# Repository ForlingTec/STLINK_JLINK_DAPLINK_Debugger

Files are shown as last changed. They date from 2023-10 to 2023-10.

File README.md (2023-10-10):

## 作者

**风陵：**

github:https://github.com/ForlingTec

CSDN:https://blog.csdn.net/weixin_42518229

**化作尘：**

https://blog.csdn.net/mbs520

## 一、产品介绍
该产品是一款基于USB2.0接口支持多个公司及多种内核的仿真器/编程器，板载了USB HUB、CPLD芯片，集成了DAPLink V2 & STLink V2 & JLink V9.7 & CDC虚拟串口/USB转串口四合一功能，硬件匹配选择的调试器并自动切换输出信号，无需重复更换固件和调试器，真正做到一机多用。

## 二、产品说明

1. 采用沁恒CH334P USB HUB全速率USB2.0集线器，使得同时支持DAPLINK、STLINK、JLINK、USB to USART(默认不焊接)连接
2. 独立3.3V 500mA的LDO稳压电源输出，为目标板提供稳定电源
3. 三大调试器共用一个外部接口，通过CPLD(AG1280Q48)智能检测并切换信号输出
4. 默认自带CDC虚拟串口，也可外接USB转串口芯片(CH340E)，默认NC
5. USB、外部输出接口均连接了静电管，避免静电损坏硬件
6. PCB采用4层双面布局，紧凑整洁，外壳体积小巧，仅40 × 40 × 13mm，外观简洁
7. 使用9P MX2.54带锁扣连接线，并附带清晰的信号标识，不用担心连接不牢固、信号连接错误
8. 每个调试器都有单独的状态指示灯，让用户对产品所处的状态一目了然

## 三、硬件框图

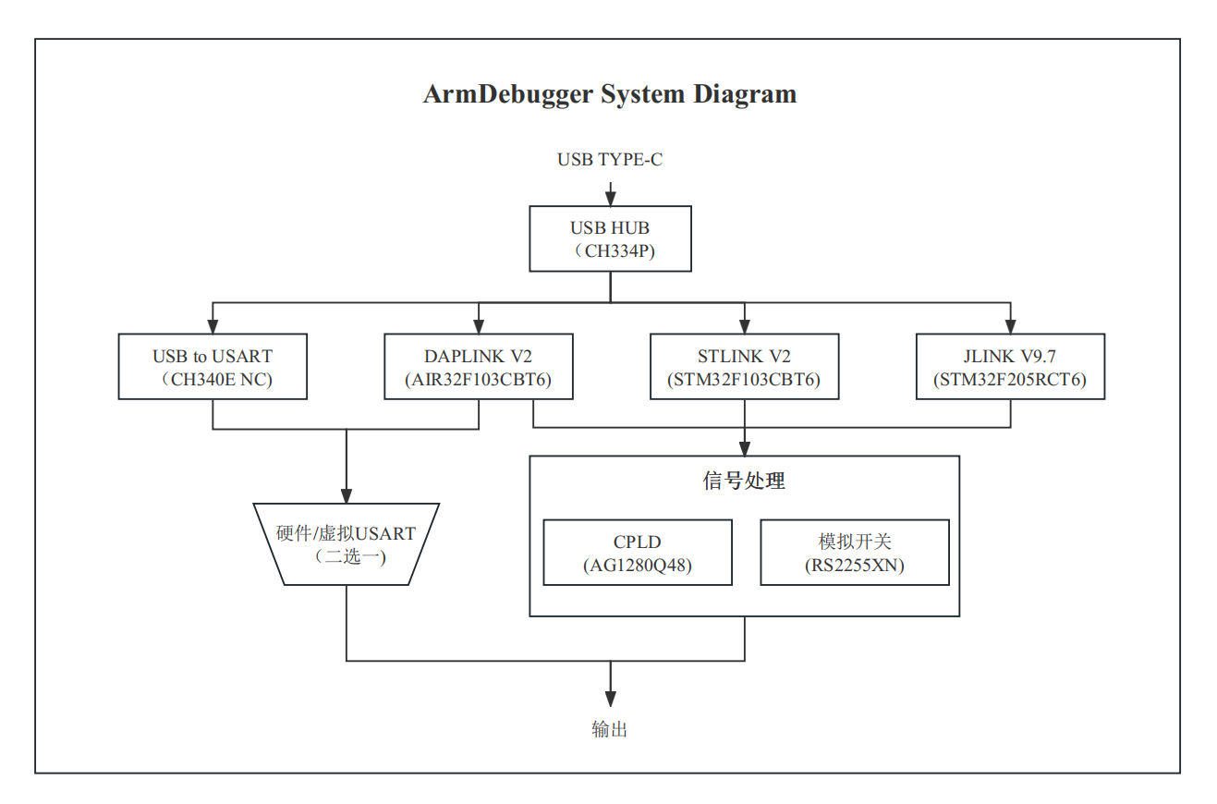
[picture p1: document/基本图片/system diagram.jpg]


## 四、产品使用

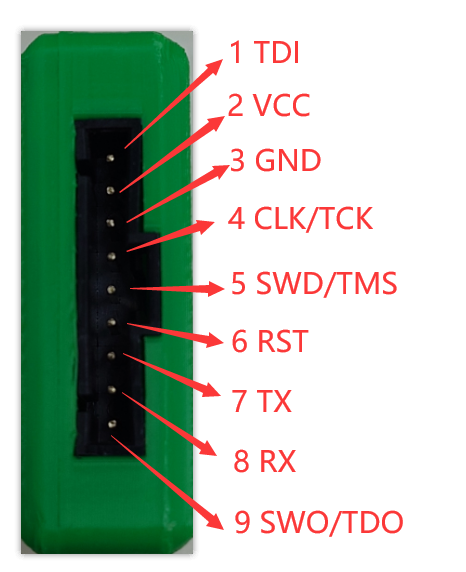
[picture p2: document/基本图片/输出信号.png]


安装完JLINK、STLINK等驱动，一般常用的KEIL/IAR等常用IDE会集成这些驱动程序，插入TYPE-C线，设备管理器显示以下新增设备

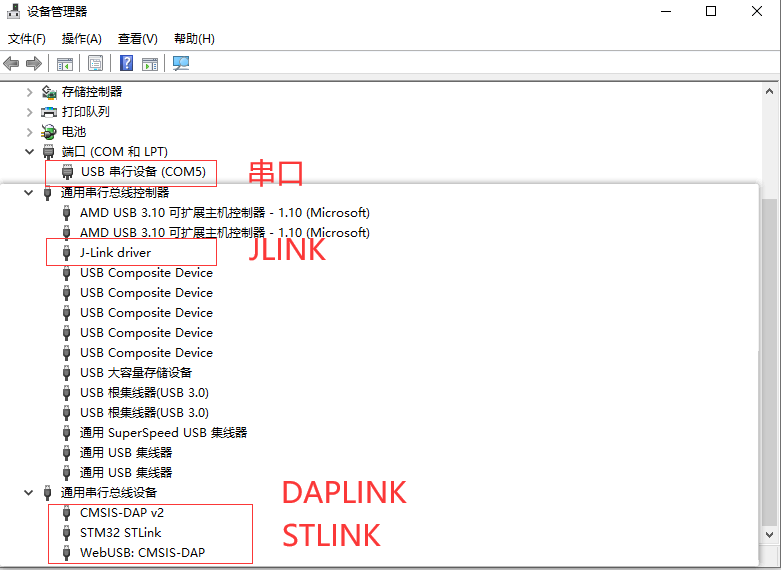
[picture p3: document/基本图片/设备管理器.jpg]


其中在KEIL中，将调试器与板子正常连接，选择调试器类型，会正常识别目标芯片(图中连接的芯片为STM32G0系列)，如下图

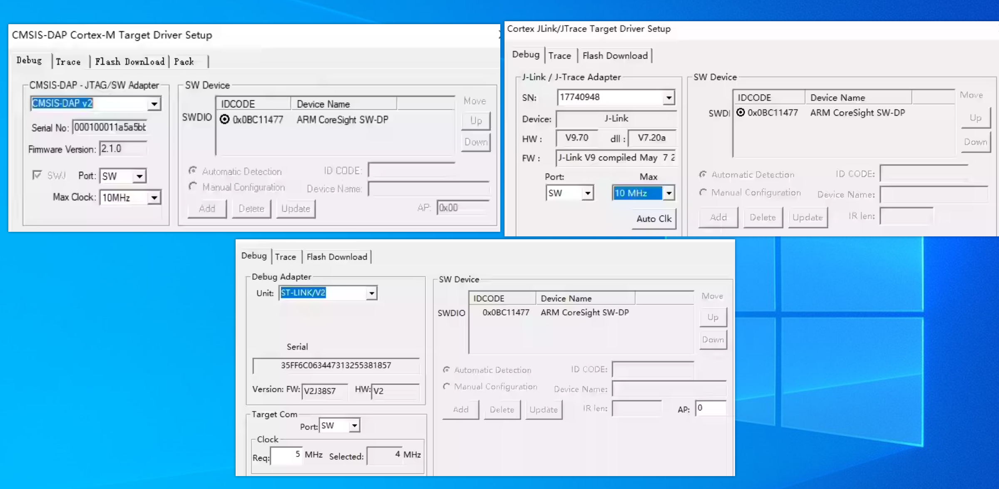
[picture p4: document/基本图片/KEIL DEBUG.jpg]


## 五、产品外观

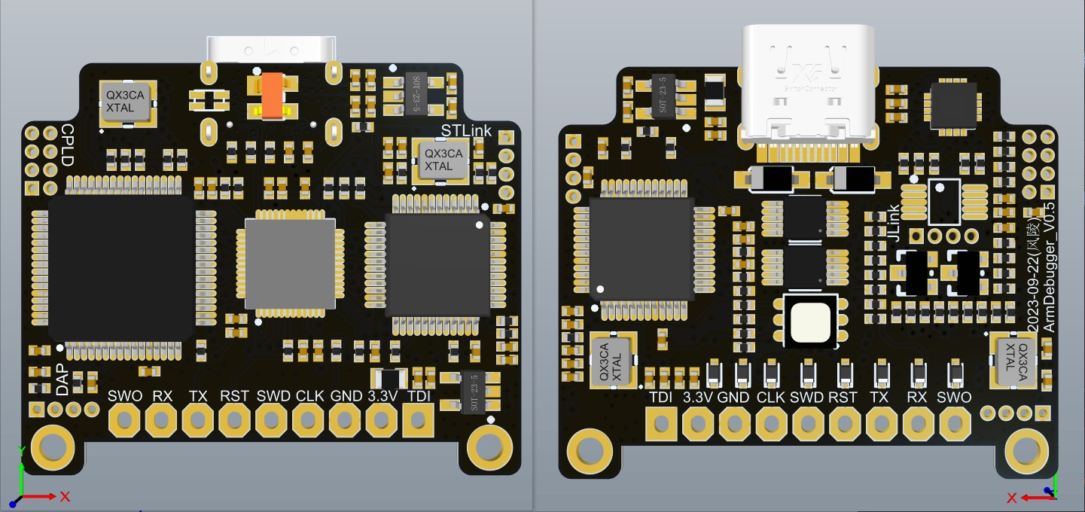
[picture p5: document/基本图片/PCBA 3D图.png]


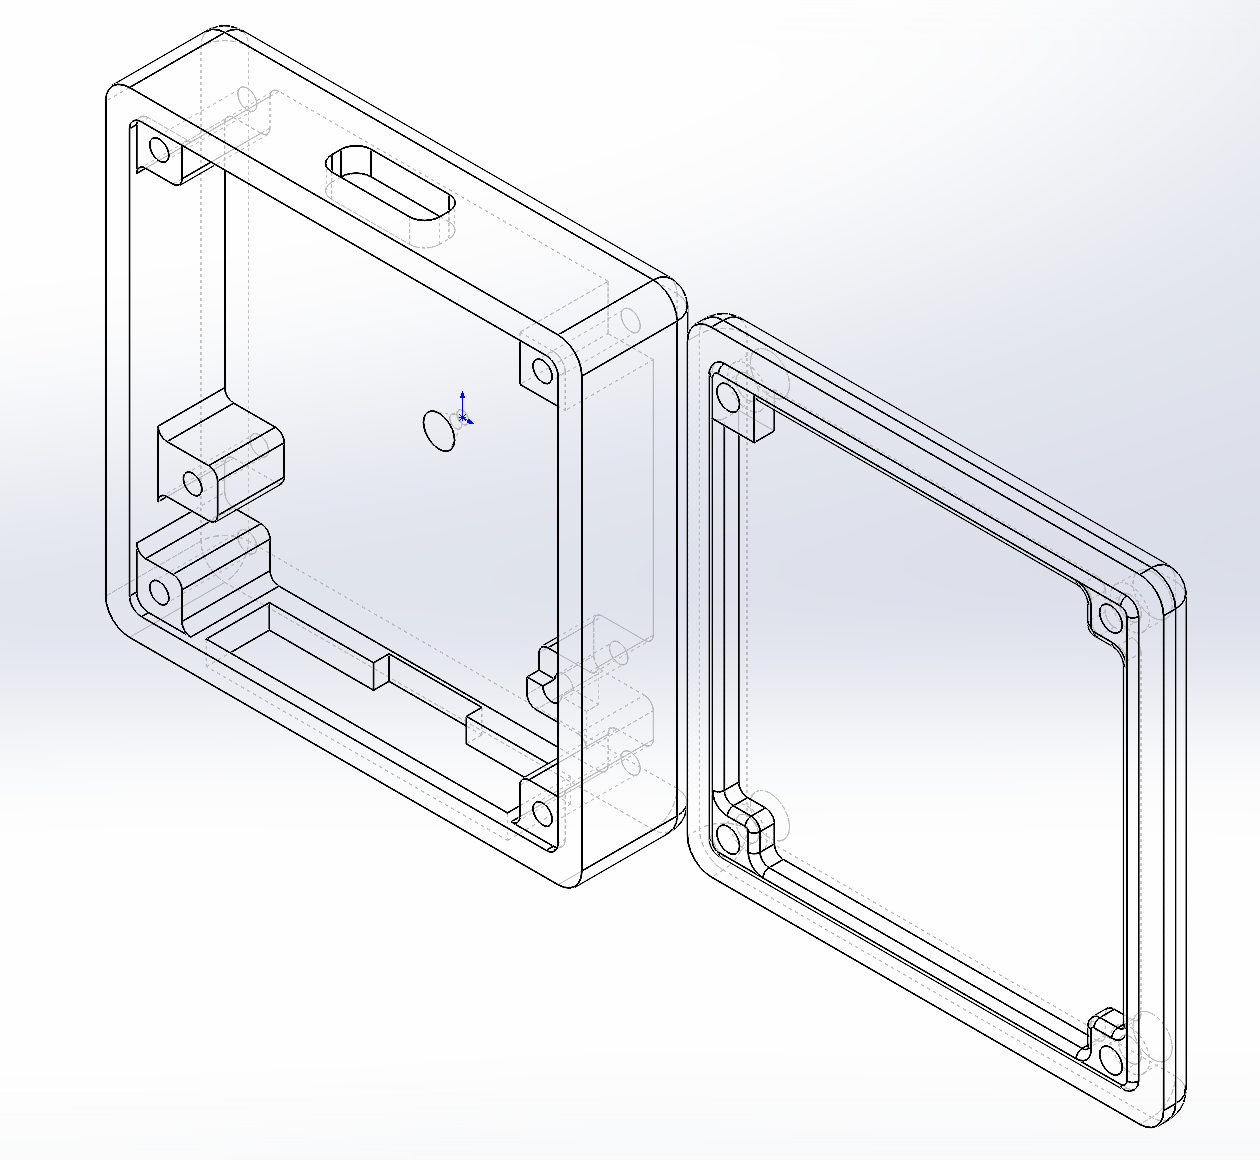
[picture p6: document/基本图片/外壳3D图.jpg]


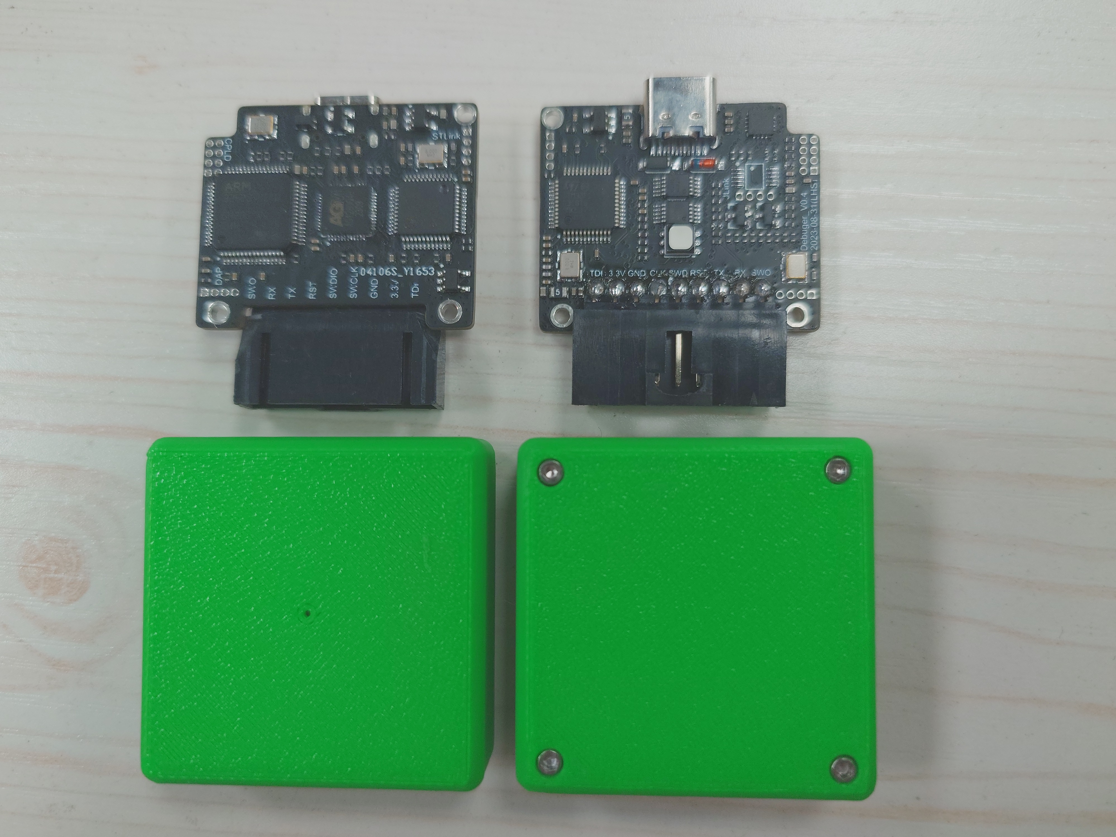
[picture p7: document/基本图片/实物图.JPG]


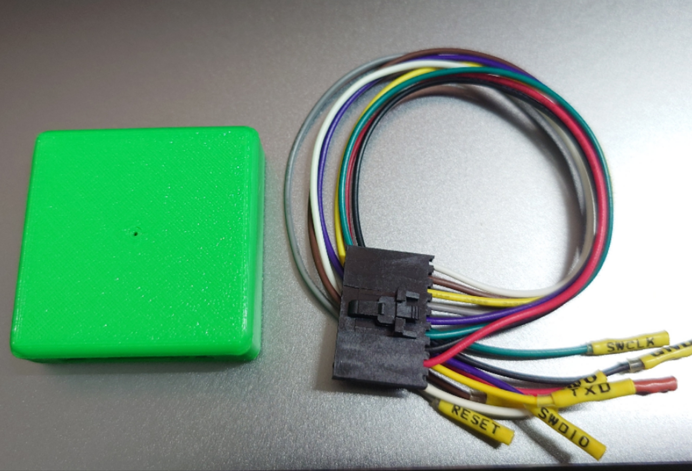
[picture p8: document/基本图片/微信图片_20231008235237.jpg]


## 六、软硬件设计

STLINK、JLINK均基于立创开源广场已有项目整理而来，DAPLINK基于合宙DAPLINK项目https://wiki.luatos.com/chips/air32f103/daplink.html整理得到。

硬件原理图与PCB工程按照模块划分，分POWER、USB HUB、STLINK、DAPLINK、JLINK、CPLD、PORT共7大模块组成。

软件设计主要是AG1280Q48这颗CPLD对信号的识别与处理，负责检测并切换当前有效的调试器，起到信号路由的作用。

CPLD软件工程用的是Quartus II + Supra混合开发,详情请查看AGM遨格芯官网:http://www.hizyuan.com/ProductDetail/2467472.html

## 七、固件烧录

需要连接TYPE-C线对硬件进行供电，推荐使用STLINK+STM32CubeProgrammer进行下载

**STM32CubeProgrammer加载bin文件，文件路径不能含有中文**

固件下载接口如下：详情请查看原理图与PCB

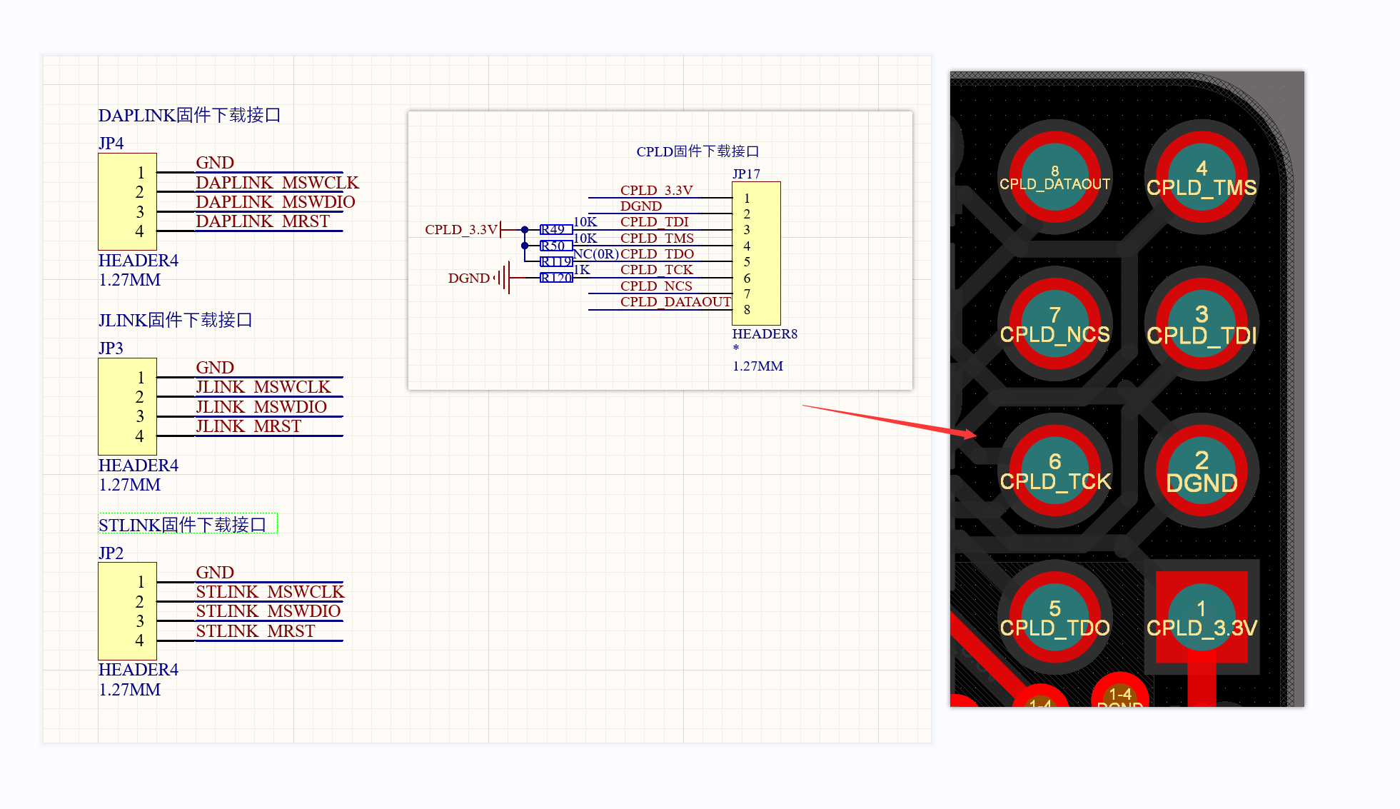
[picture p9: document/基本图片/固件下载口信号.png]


### STLINK

------

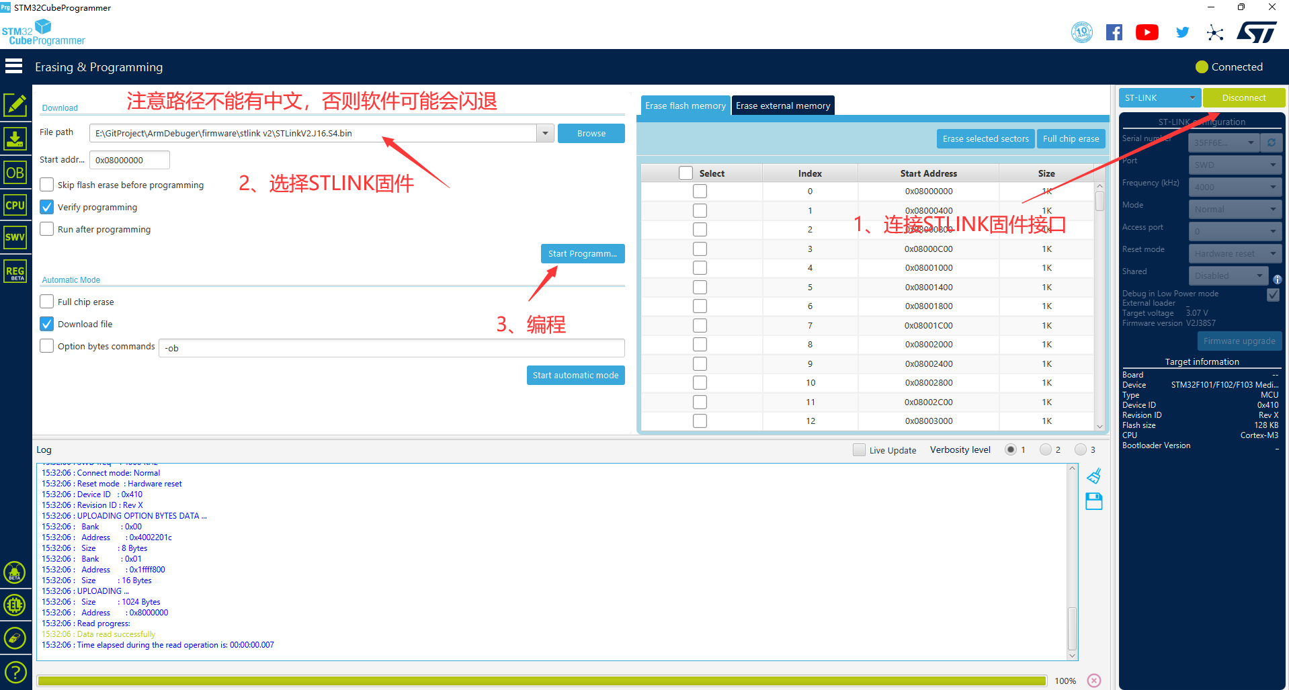
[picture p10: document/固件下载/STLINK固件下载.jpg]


### DAPLINK

------

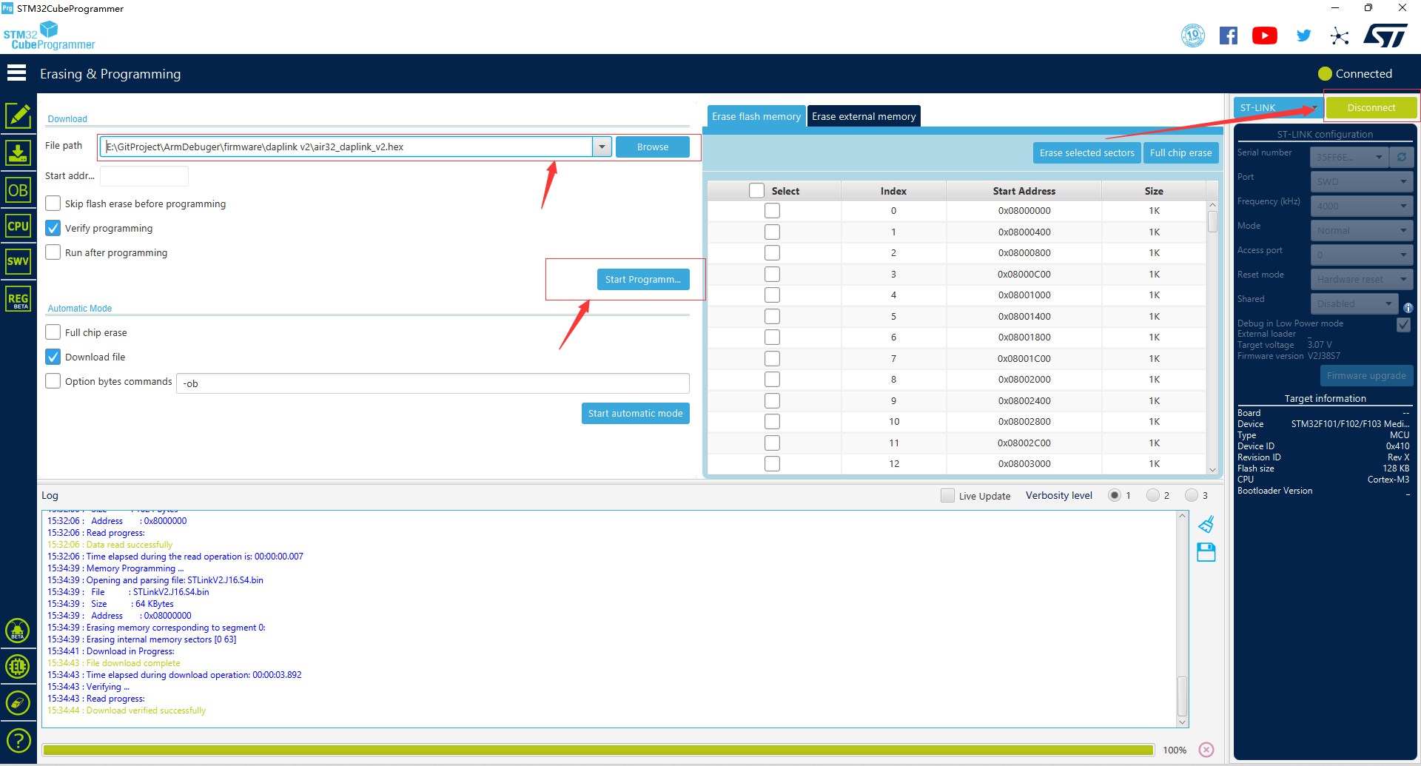
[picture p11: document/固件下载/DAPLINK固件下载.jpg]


### JLINK

------

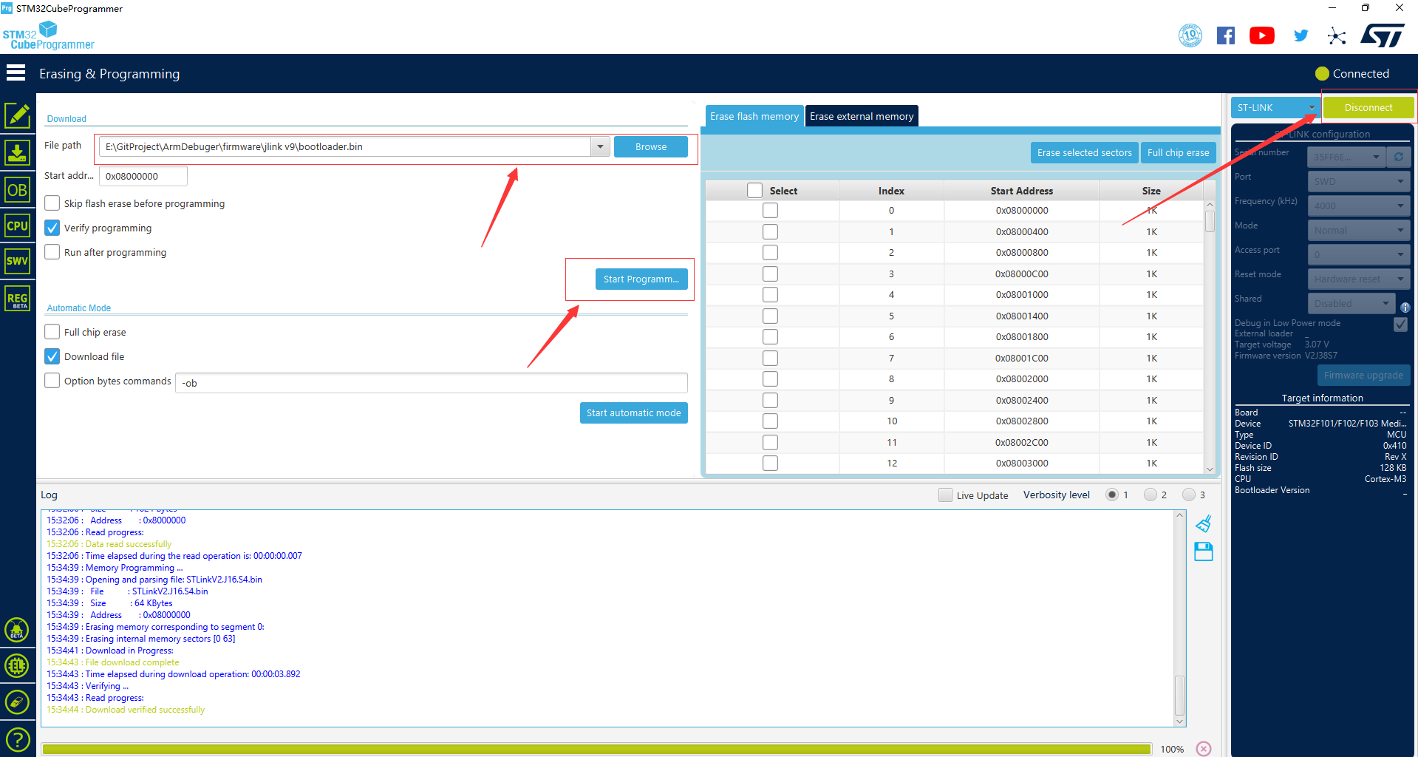
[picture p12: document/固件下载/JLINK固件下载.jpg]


### CPLD

------

1. 用Supra打开软件工程，点击左上角的“file - project - open project - AG1280.proj”，然后点击倒数第二个图标“program into device”打开烧录界面

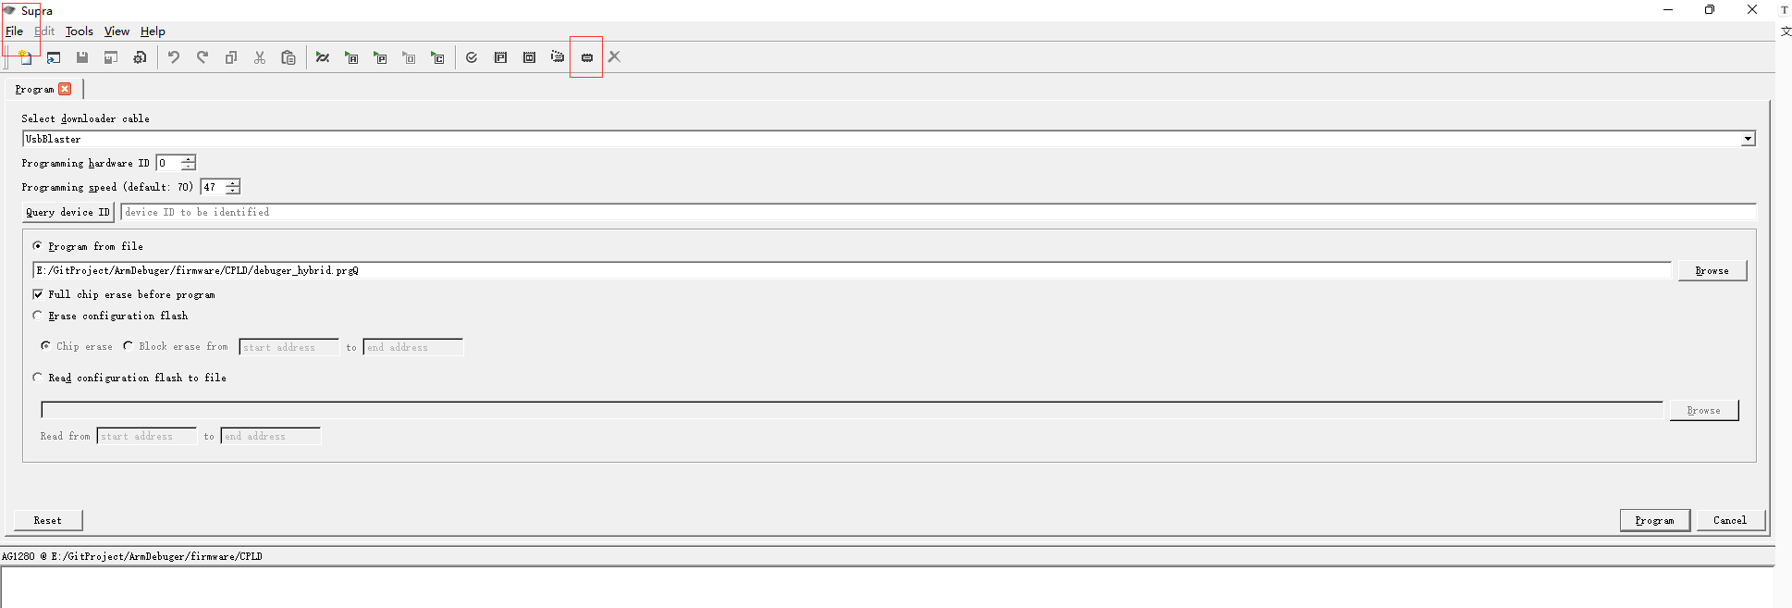
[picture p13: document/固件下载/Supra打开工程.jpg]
   

2. 将USB-blaster按照原理图上的信号连接好，按照以下步骤烧录CPLD固件

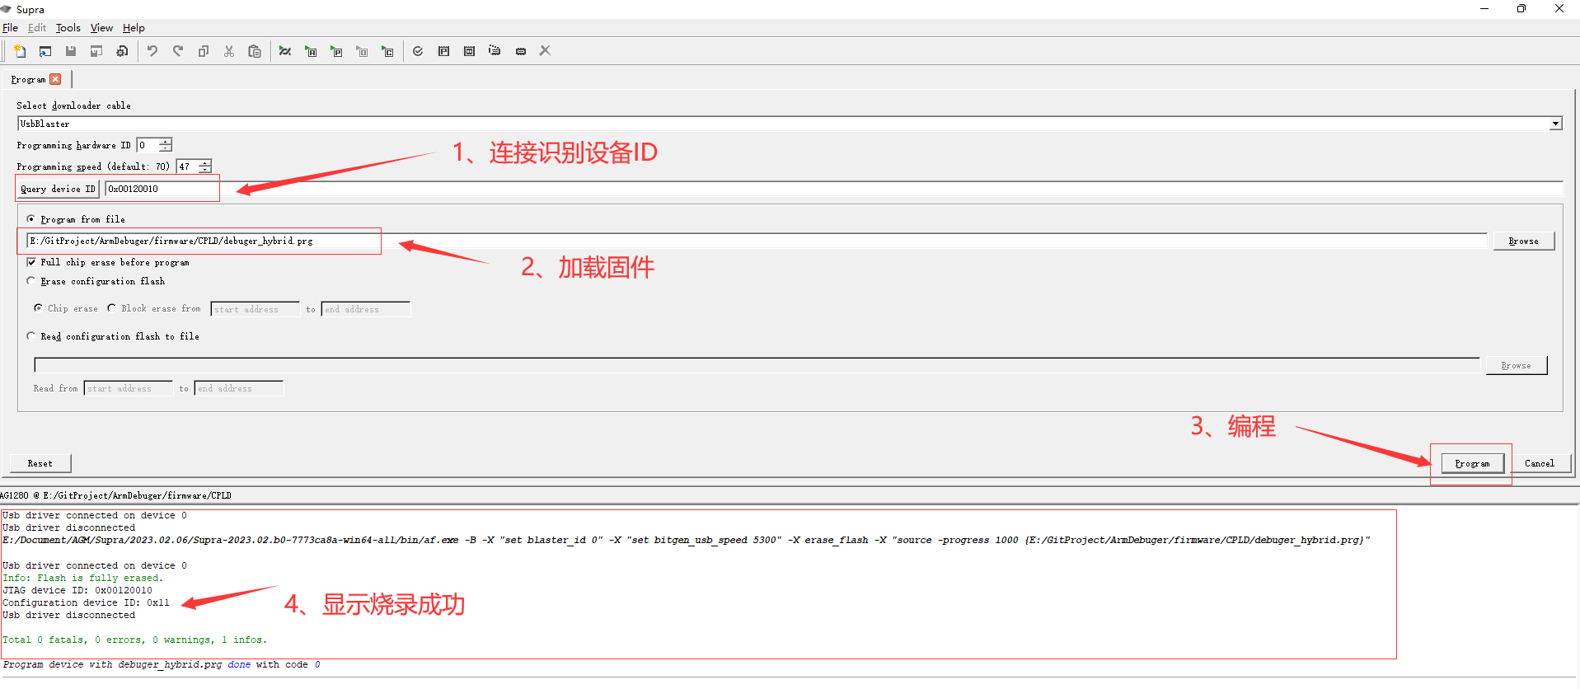
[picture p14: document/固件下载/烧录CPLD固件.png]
   

## 八、固件升级、License

步骤七烧录完固件后，重新插拔USB，这时候windows设备管理器就可以正常识别出设备了，可以查看**<<四、产品说明>>**的图片

### STLINK

------

因为步骤七烧录的STLINK的固件很旧，需要用STM32CubeProgrammer更新固件。

**1、重新打开STM32CubeProgrammer软件，进入固件升级界面**

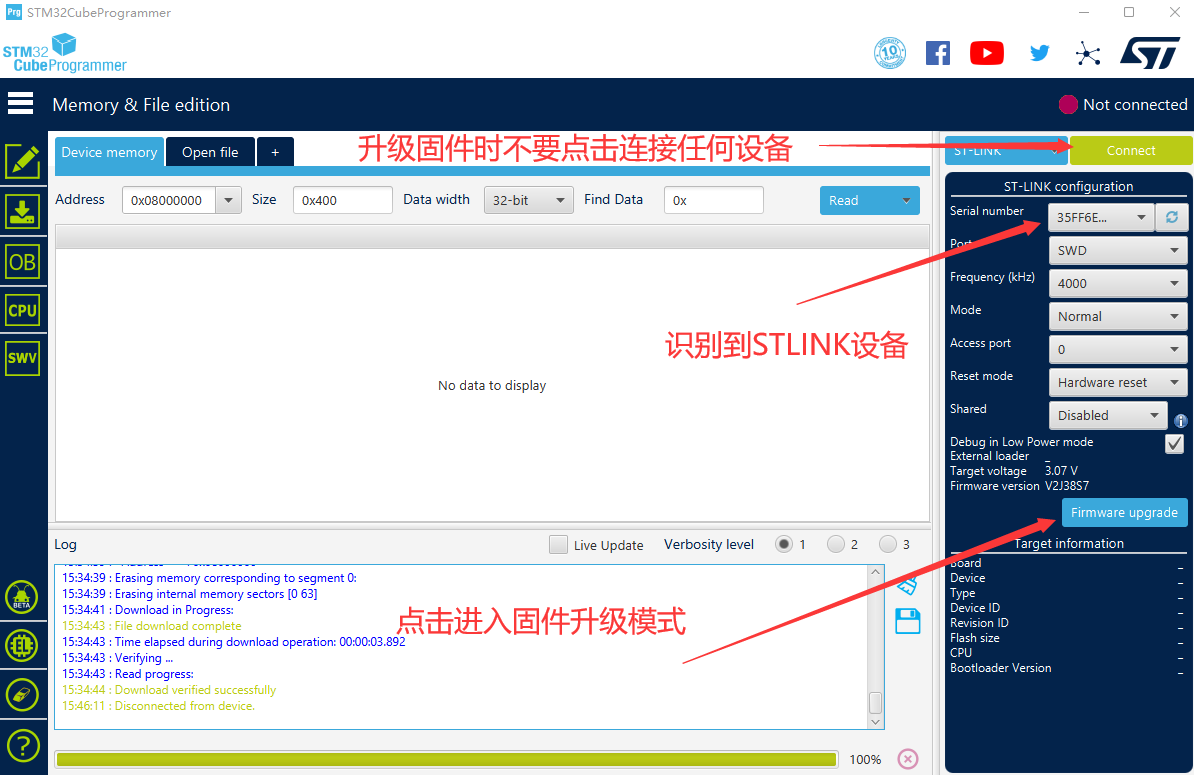
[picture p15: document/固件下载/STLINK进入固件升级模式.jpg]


**2、点击“Open in update mode”进入升级模式，识别到版本信息后点击“upgrade”升级按钮，等待升级完毕**

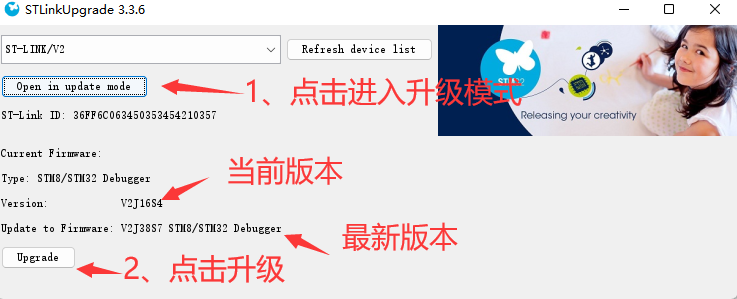
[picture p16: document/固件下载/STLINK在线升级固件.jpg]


### JLINK

------

**注意事项：JLINK驱动不能用V7.58以上版本，因为修复了盗版的BUG，容易掉固件，推荐用V7.2a及以下驱动版本**

烧录的JLINK固件仅仅是bootloader引导程序，需要用JLINK commander命令行先更新App固件，然后再添加license许可证，步骤如下：

1. 运行"jlink_license_creator.exe"程序

2. 如果没有“JLink_V6.32b.exe”、“JLinkARM.dll”这两个文件，直接点击“打开JLINK”按钮生成

3. 选择硬件版本，推荐用JLINK V9.7

4. 点击“生成”按钮，生成License SN号

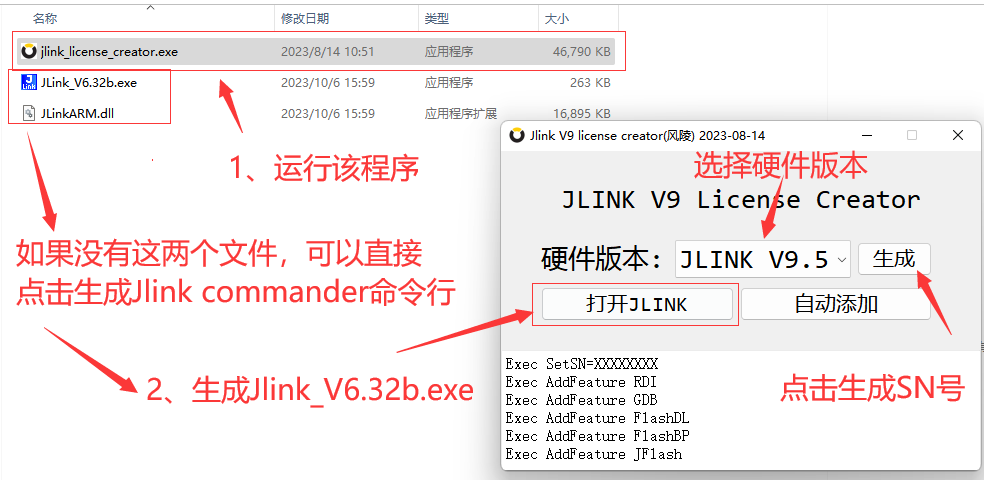
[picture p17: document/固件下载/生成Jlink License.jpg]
   

5. 运行“JLink_V6.32b.exe”程序，这时候会更新JLINK App固件，更新App完毕后将生成的S/N号和命令分别一条一条添加进去

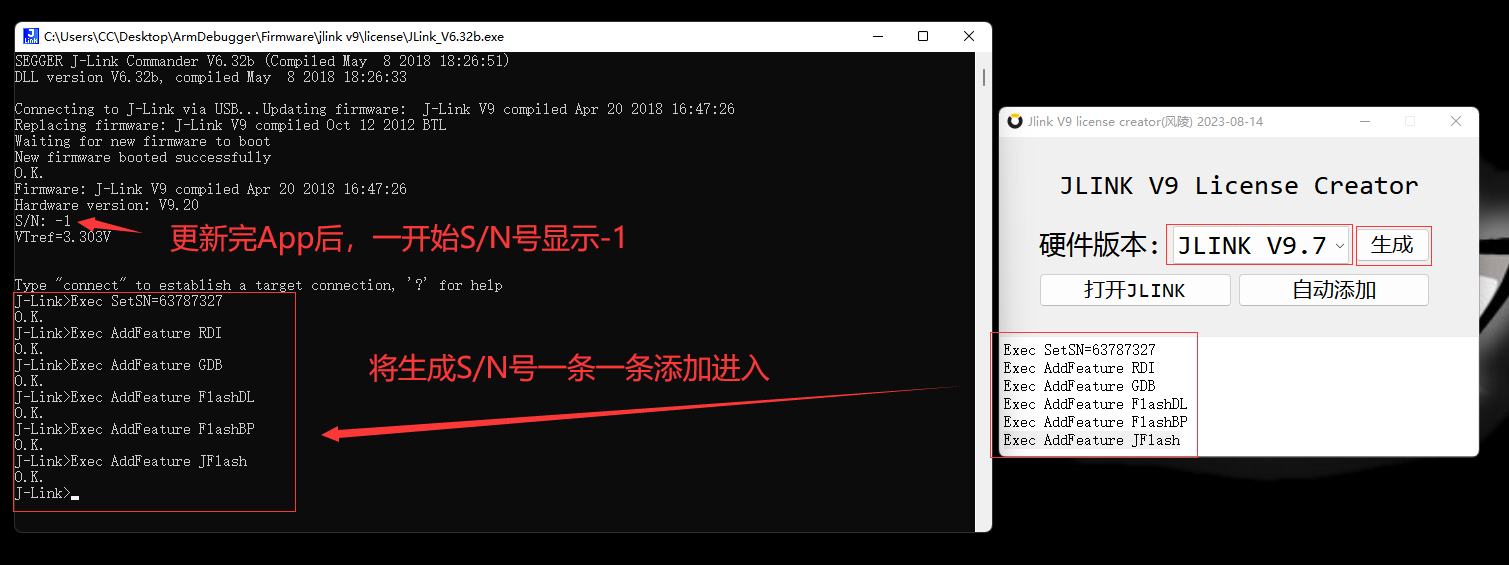
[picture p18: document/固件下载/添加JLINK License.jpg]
   

6. 重新插拔USB，并重新打开“JLink_V6.32b.exe”程序，识别到以下信息

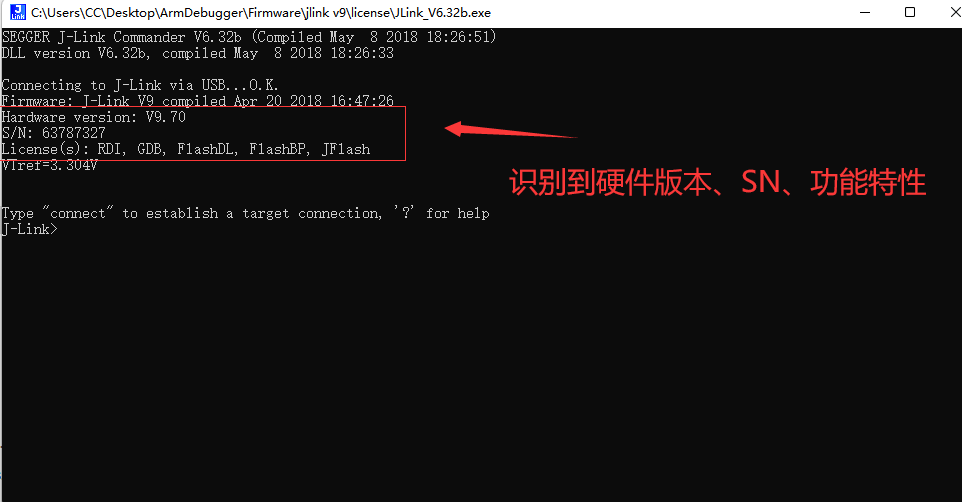
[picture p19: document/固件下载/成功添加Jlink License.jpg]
   

## 九、链接

bilibi哔哩哔哩：

立创开源广场：https://oshwhub.com/mr.liu0710/DAPLink-STLink-JLINK-chuan-kou-s

GitHub：https://github.com/ForlingTec/STLINK_JLINK_DAPLINK_Debugger.git

CSDN：https://blog.csdn.net/weixin_42518229?spm=1000.2115.3001.5343

淘宝链接：https://item.taobao.com/item.htm?id=742546183124

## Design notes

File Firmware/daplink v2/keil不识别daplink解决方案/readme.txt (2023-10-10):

https://developer.arm.com/documentation/ka003663/1-0/?lang=en

keil v5.28及以下版本不支持winUSB

解决方案：
方案一：升级keil版本到V5.29及以上
方案二：点击上述链接，下载4170.zip文件，将里面的CMSIS_DAP.dll替换安装目录ARM\BIN\的同名驱动文件，默认路径在C:\Program Files\keil v5\ARM\BIN

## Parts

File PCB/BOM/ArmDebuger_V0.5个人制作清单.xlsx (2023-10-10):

Comment | Designator | Footprint | Quantity | 单价(￥) | 总价(￥) | 立创商城/淘宝链接
AG1280Q48 | U35 | QFN6X6-48 | 1 | 9 | 9 | 深圳市优益芯电子科技 (https://m.tb.cn/h.5UjIJER?tk=o2YQWaF6f0s)
AIR32F103CBT6 | U5 | LQFP48_L | 1 | 3.8 | 3.8 | 上海合宙LuatOS官方企业店 (https://item.taobao.com/item.htm?spm=a1z10.5-c-s.w4002-24045920841.17.68ac5f96B1VFWF&id=676775991179)
CH334P | U6 | QFN-16 | 1 | 3.19 | 3.19 | 深圳市优益芯电子科技 (https://item.taobao.com/item.htm?id=723721911510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)
STM32F103CBT6TR | U3 | LQFP48_L | 1 | 6.5 | 6.5 | 深圳市优益芯电子科技 (https://m.tb.cn/h.5UjFpJ6?tk=nM8UWaFiXVg)
STM32F205RET6TR | U4 | LQFP64_L | 1 | 15 | 15 | 深圳市优益芯电子科技 (https://m.tb.cn/h.551KmY1?tk=9z7YWaFRN6v)
MMBT5401 | Q1 | SOT-23 | 1 | 0.08698 | 0.08698 | C8326
B5819W | D1 | SOD-123 | 1 | 0.169983 | 0.169983 | C8598
1K | R37, R120 | 0402R | 2 | 0.003069 | 0.006138 | C11702
0R | R4, R5, R36, R61, R65 | 0402R | 5 | 0.002303 | 0.011515 | C21376
1R | R16, R19 | 0402R | 2 | 0.003882 | 0.007764 | C25086
10K | R8, R9, R14, R15, R17, R18, R20, R21, R22, R23, R24, R25, R27, R29, R32, R34, R40, R42, R43, R45, R46, R47, R49, R50, R51, R52, R54, R58, R59, R63, R68 | 0402R | 31 | 0.00294 | 0.09114 | C25744
1.5K | R12, R13 | 0402R | 2 | 0.003308 | 0.006616 | C25867
4.7K | R7, R53 | 0402R | 2 | 0.003056 | 0.006112 | C25900
5.1K | R2, R3 | 0402R | 2 | 0.003146 | 0.006292 | C25905
106/X5R/10V | C2, C3, C5, C6, C13, C14, C19, C38, C39, C46, C47, C49, C50, C51, C52, C53, C54 | 0402C | 17 | 0.016575 | 0.281775 | C29266
104/X7R/16V | C1, C4, C7, C10, C17, C18, C20, C21, C22, C23, C24, C25, C26, C27, C28, C29, C30, C31, C32, C33, C34, C35, C36, C37, C40, C41, C42, C43, C44, C45, C48, C105, C172, C223, C224, C227, C228, C229 | 0402C | 38 | 0.005098 | 0.193724 | C60474
FUSE 6V/500mA | F1, F2 | 0805R | 2 | 0.249616 | 0.499232 | C66452
ME6211C33 | U2, U9 | SOT-23-5 | 2 | 0.290229 | 0.580458 | C82942
100R | R6, R10, R11, R26, R31, R33, R38, R39, R41, R44, R48, R55, R56, R57, R60, R69 | 0402R | 16 | 0.003758 | 0.060128 | C106232
MM1Z5V1 | D9 | SOD-123 | 1 | 0.065982 | 0.065982 | C112534
12MHZ | Y1, Y3 | SMT-3225 | 2 | 0.339706 | 0.679412 | C133334
SDCW2012-2-121TF | L1 | SDCW2012-2 | 1 | 0.427565 | 0.427565 | C145052
22P/C0G/50V | C8, C9, C11, C12, C15, C16 | 0402C | 6 | 0.024929 | 0.149574 | C167428
ME6219C12M5G | U25 | SOT-23-5 | 1 | 0.660675 | 0.660675 | C236651
SR05-02A | U1 | SOT-143 | 1 | 0.3252 | 0.3252 | C521962
RS2255XN | U8, U10 | MSOP-10 | 2 | 1.6422 | 3.2844 | C783421
LED-RGB-SMD | D2 | SMD3535 | 1 | 0.28 | 0.28 | C784546
USB-type-C_2 | JP1 | USB-Type-C-SMT | 1 | 0.328675 | 0.328675 | C2765186
S8050 | Q3 | SOT-23 | 1 | 0.042 | 0.042 | C2891804
KESD3.3V52D-C | ED1, ED2, ED3, ED4, ED5, ED6, ED7, ED8 | SOD-523 | 8 | 0.128254 | 1.026032 | C2892515
1M | R1 | 0402R | 1 | 0.002484 | 0.002484 | C3152068
8MHZ | Y2, Y4 | SMT-3225 | 2 | 0.555918 | 1.111836 | C5308002
立创商城运费 |  |  | 1 | 8 | 8
合计 | 55.881692
Comment | 总价(￥) | 嘉立创/淘宝链接
绿色4层PCB | 30 | 嘉立创下单助手
激光钢网 | 60 | 嘉立创下单助手
3D打印外壳 | 7 | 嘉立创下单助手
MX2.54 9P 一套公母头 | 4.46 | risym旗舰店 (https://m.tb.cn/h.5UQ72Bb?tk=k6t9WaFDxjZ)
MX2.54 标识线材 | 20 | MicroGo网站产品 (https://m.tb.cn/h.55s2OJx?tk=VnEzWavamaa)
合计 | 121.46
Comment | 总价(￥) | 嘉立创/淘宝链接
黑色4层PCB | 60 | 嘉立创下单助手
激光钢网 | 60 | 嘉立创下单助手
3D打印外壳 | 7 | 嘉立创下单助手
MX2.54 9P 一套公母头 | 4.46 | risym旗舰店 (https://m.tb.cn/h.5UQ72Bb?tk=k6t9WaFDxjZ)
MX2.54 标识线材 | 20 | MicroGo网站产品 (https://m.tb.cn/h.55s2OJx?tk=VnEzWavamaa)
合计 | 151.46
类型 | 总价(￥)
绿色PCB款 | 177.341692
黑色PCB款 | 207.341692

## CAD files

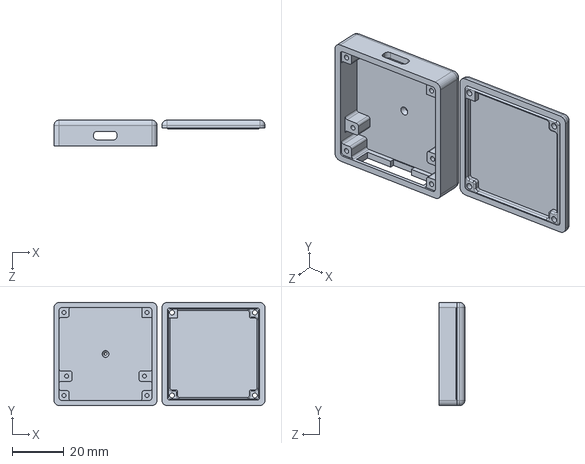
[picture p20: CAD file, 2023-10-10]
3D/ArmDebugger_v0.5.SLDPRT
81.9 x 40.0 x 10.0 mm

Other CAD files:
3D/ArmDebugger_v0.5.STL

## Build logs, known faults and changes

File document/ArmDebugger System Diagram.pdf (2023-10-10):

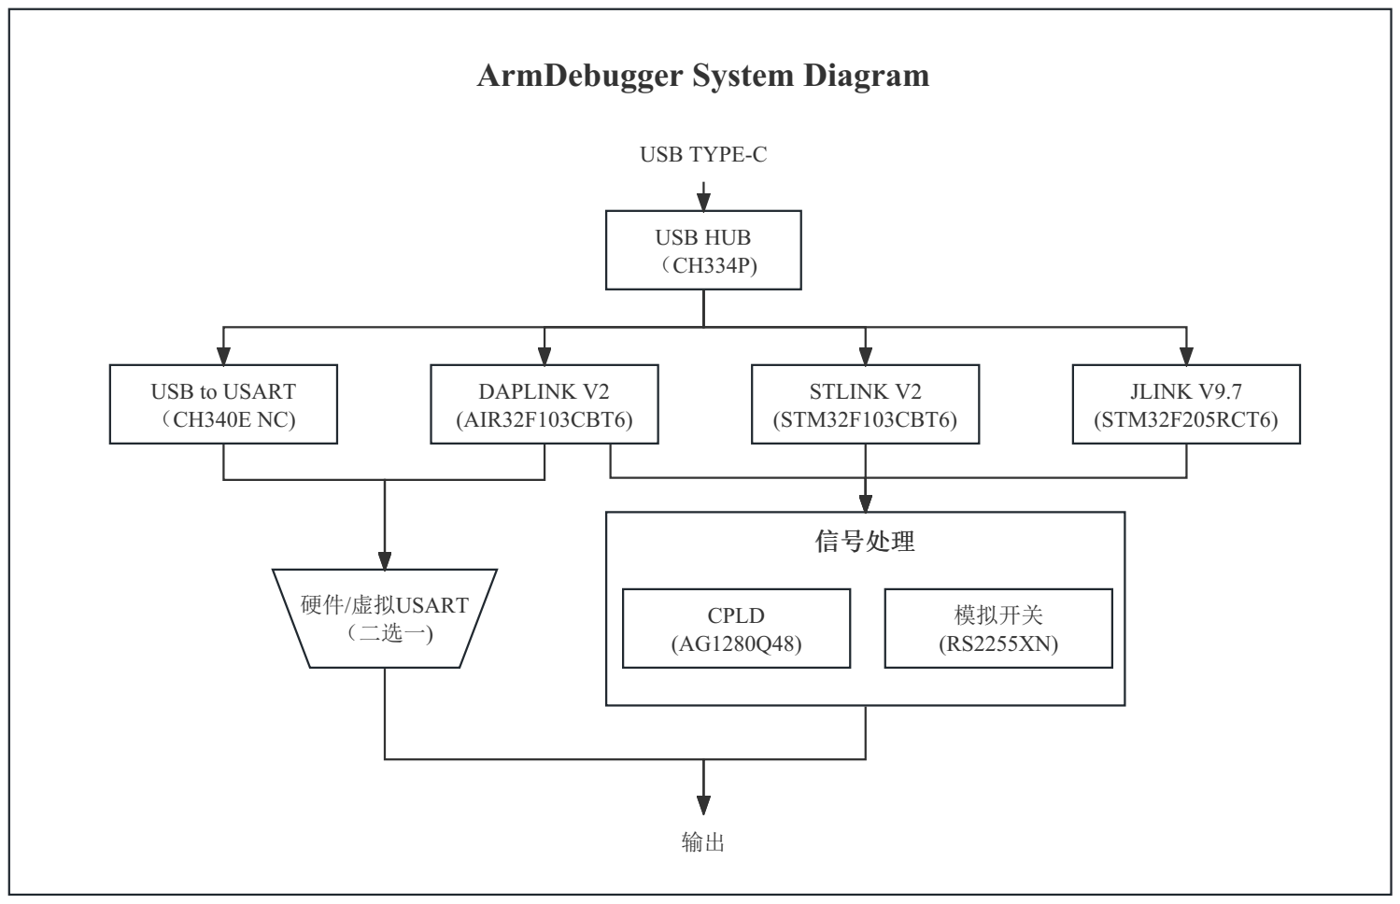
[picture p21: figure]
ArmDebugger System Diagram; USB HUB （CH334P); USB to USART （CH340E NC); STLINK V2 (STM32F103CBT6); DAPLINK V2 (AIR32F103CBT6); JLINK V9.7 (STM32F205RCT6); 硬件/虚拟USART （二选一); CPLD (AG1280Q48); 模拟开关 (RS2255XN); 信号处理; USB TYPE-C
